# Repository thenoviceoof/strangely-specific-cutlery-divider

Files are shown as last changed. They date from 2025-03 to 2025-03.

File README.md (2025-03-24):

This is a 2D OpenSCAD plan for a cutlery divider for a very specific drawer.

The only files kept reasonably up to date are dividers.scad and dividers.dxf.

# Dimension measurements

Drawer is 248x489mm (9.76x19.25in).

2nd set of measurements is 248-249, and 483-485. Difficult to make accurate measurements in such a long drawer without taking the drawer out.
Depth is 102mm.

# Requirements

3 columns: 2 split into 2 for forks and spoons, 1 left undivided, for table knives and long chopsticks.

# Market Research

Based on [Serious Eats Review of drawer organizers](https://www.seriouseats.com/best-kitchen-drawer-organizers-8421933):

- [Option 1](https://www.amazon.com/Joseph-85119-DrawerStore-Organizer-Silverware/dp/B072R6CLRC/) Target house has way too much cutlery to fit in this narrow option.
- [Example 1](https://www.amazon.com/dp/B09B1CZVWR/): minimum width dimension is 9.8". It is theoretically possible to fit it by breaking off the expansion bit, but I'm not going to spend $22 to find out for sure.
- [Example 2](https://www.amazon.com/dp/B007B8RKJI): width dimension is 11".

Commercial versions appear to be 2.5-3in deep.

# Design considerations

[Ponoko article on kerf](https://help.ponoko.com/en/articles/4442594-how-much-material-does-the-laser-burn-away), for 3mm acrylic is 0.2mm.

[SendCutSend claims to compensate for kerf automatically](https://sendcutsend.com/blog/what-is-kerf-in-laser-cutting/).

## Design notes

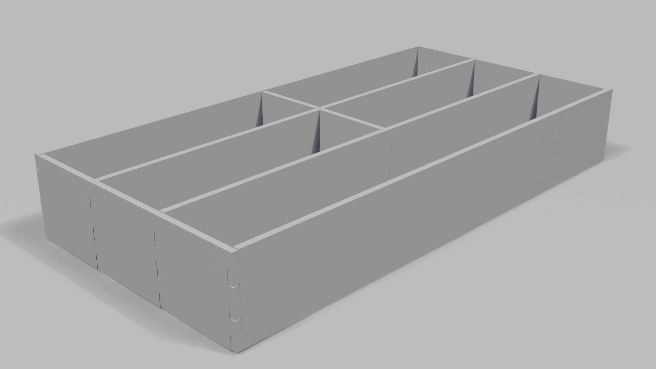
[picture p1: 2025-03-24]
img/dividers_together.png

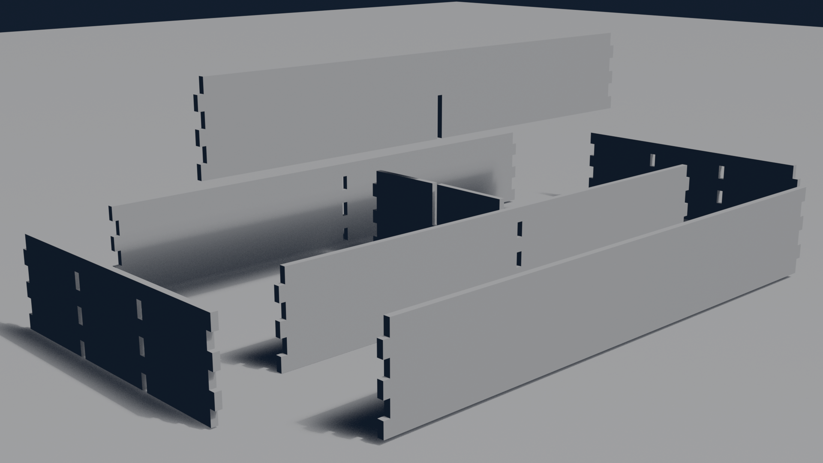
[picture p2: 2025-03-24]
img/dividers_exploded.png

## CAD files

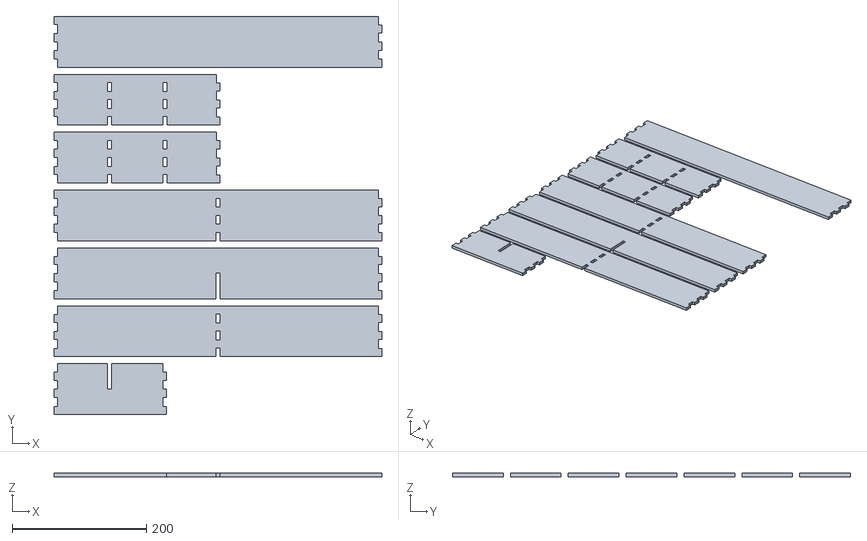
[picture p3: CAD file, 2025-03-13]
dividers.stl
488.6 x 593.0 x 5.40

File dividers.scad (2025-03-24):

// All values in mm.

/* ####################
 * Definitions.
 * #################### */

// Downsize a bit to make sure there's space.
// We can always add padding, but reducing size is basically impossible.
W = 248 - 10;
L = 483 - 20;
// 3in in height.
H = 25.4 * 2.8;

// How thick the material is.
MAT_THICK = 3;
// How wide the laser is.
// Ponoko: 0.2mm beam width.
// SendCutSend: handled automatically.
KERF = 0.1;
// Cut away just a little more, to make assembly easier/possible.
// SendCutSend MDF Tab/Slot tolerance is 0.01in, 0.25mm.
// It is possible this should be 1/2x 0.25mm.
SLOP = 0.25;
// Total adjustments: positive values cut away more.
ADJ = SLOP - KERF;

EXT_PAD = 5;

/* ####################
 * Utilities
 * #################### */

// The project is simple enough that we can get away with having all joins "point one way".
// Creates a 3 vs 3 finger box join. Fingers point to -x.
ext_box_join_a = [
    [MAT_THICK + ADJ, ADJ],
    [MAT_THICK + ADJ, 1/6 * H + ADJ],
    [ADJ,             1/6 * H + ADJ],
    [ADJ,             2/6 * H - ADJ],
    [MAT_THICK + ADJ, 2/6 * H - ADJ],
    [MAT_THICK + ADJ, 3/6 * H + ADJ],
    [ADJ,             3/6 * H + ADJ],
    [ADJ,             4/6 * H - ADJ],
    [MAT_THICK + ADJ, 4/6 * H - ADJ],
    [MAT_THICK + ADJ, 5/6 * H + ADJ],
    [ADJ,             5/6 * H + ADJ],
    [ADJ,             H - ADJ],
];
// The other side of the join.
ext_box_join_b = [ for (v = ext_box_join_a) [-v[0], -v[1] + H]];
// Bottom tooth for the left side.
ext_box_join_c = [ for (v = ext_box_join_a) [v[0], -v[1] + H]];

// "Interior" box join.
function poly_square(p1, p2) = [
    [p1[0], p1[1]],
    [p1[0], p2[1]],
    [p2[0], p2[1]],
    [p2[0], p1[1]]
];
int_box_join = concat(
    poly_square([-MAT_THICK/2 - ADJ, ADJ],
                [MAT_THICK/2 + ADJ,  1/6 * H + ADJ]),
    poly_square([-MAT_THICK/2 - ADJ, 2/6 * H - ADJ],
                [MAT_THICK/2 + ADJ,  3/6 * H + ADJ]),
    poly_square([-MAT_THICK/2 - ADJ, 4/6 * H - ADJ],
                [MAT_THICK/2 + ADJ,  5/6 * H + ADJ])
);

// Cross lap join.
cross_lap_join = poly_square([-MAT_THICK/2 - ADJ, ADJ],
                             [MAT_THICK/2 + ADJ, H / 2 + ADJ]);

/* ####################
 * Actual pieces
 * #################### */

// Right piece.
RIGHT_VEC = concat(
    ext_box_join_a,
    [ for (v = ext_box_join_b) [v[0] + L, v[1]]]
);
projection()
translate([0, 3*(H+EXT_PAD), 0])
linear_extrude(height=MAT_THICK)
polygon(RIGHT_VEC);

// Front piece.
FRONT_VEC = concat(
    ext_box_join_a,
    [ for (v = ext_box_join_b) [v[0] + W, v[1]]],
    [ for (v = int_box_join) [v[0] + W/3, v[1]]],
    [ for (v = int_box_join) [v[0] + 2*W/3, v[1]]]
);
FRONT_PATHS = [
    concat(
        [for (i = [0:11]) i],
        [for (i = [12:23]) i],
        // Square cutouts.
        [for (i = [39:-1:36]) i],
        [for (i = [27:-1:24]) i]
    ),
    [for (i = [28:31]) i],
    [for (i = [32:35]) i],
    [for (i = [40:43]) i],
    [for (i = [44:47]) i]
];
projection()
translate([W + EXT_PAD/2, 4*(H+EXT_PAD), 0])
linear_extrude(height=MAT_THICK)
polygon(FRONT_VEC, FRONT_PATHS);
    
// Use the same geometry for the back.
projection()
translate([0, 4*(H+EXT_PAD), 0])
linear_extrude(height=MAT_THICK)
polygon(FRONT_VEC, FRONT_PATHS);

// Left piece.
LEFT_VEC = concat(
    ext_box_join_a,
    [ for (v = ext_box_join_b) [v[0] + L, v[1]]],
    [ for (v = int_box_join) [v[0] + L/2, v[1]]]
);
LEFT_PATHS = [
    concat(
        [for (i = [0:11]) i],
        [for (i = [12:23]) i],
        // Square cutouts.
        [for (i = [27:-1:24]) i]
    ),
    [for (i = [28:31]) i],
    [for (i = [32:35]) i]
];
projection()
translate([0, 2*(H+EXT_PAD), 0])
linear_extrude(height=MAT_THICK)
polygon(LEFT_VEC, LEFT_PATHS);

// Column, left.
COL_LEFT_VEC = concat(
    ext_box_join_c,
    [ for (v = ext_box_join_b) [v[0] + L, v[1]]],
    [ for (v = cross_lap_join) [v[0] + L/2, v[1]]]
);
COL_LEFT_PATHS = [
    concat(
        [for (i = [11:-1:0]) i],
        [for (i = [12:23]) i],
        // Fold join.
        [for (i = [27:-1:24]) i]
    )
];
projection()
translate([0, 1*(H+EXT_PAD), 0])
linear_extrude(height=MAT_THICK)
polygon(COL_LEFT_VEC, COL_LEFT_PATHS);

// Column, right.
COL_RIGHT_VEC = concat(
    ext_box_join_c,
    [ for (v = ext_box_join_b) [v[0] + L, v[1]]],
    [ for (v = int_box_join) [v[0] + L/2, v[1]]]
);
COL_RIGHT_PATHS = [
    concat(
        [for (i = [11:-1:0]) i],
        [for (i = [12:23]) i],
        // Square cutouts.
        [for (i = [27:-1:24]) i]
    ),
    [for (i = [28:31]) i],
    [for (i = [32:35]) i]
];
projection()
translate([0, 0, 0])
linear_extrude(height=MAT_THICK)
polygon(COL_RIGHT_VEC, COL_RIGHT_PATHS);

// Cross piece.
CROSS_VEC = concat(
    ext_box_join_c,
    [ for (v = ext_box_join_b) [v[0] + 2/3 * W + MAT_THICK/2, v[1]]],
    [ for (v = cross_lap_join) [v[0] + 1/3 * W, v[1] + H / 2]]
);
CROSS_PATHS = [
    concat(
        [for (i = [11:-1:0]) i],
        // Cross lap.
        [25, 24, 27, 26],
        [for (i = [12:23]) i]
    )
];
projection()
translate([L+EXT_PAD + H, 0, 0])
rotate(90)
linear_extrude(height=MAT_THICK)
polygon(CROSS_VEC, CROSS_PATHS);

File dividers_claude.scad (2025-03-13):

// Drawer Divider System with Cross Lap and Box Joints
// Dimensions are in mm

// Main drawer dimensions
drawer_length = 489;
drawer_depth = 248;
divider_height = 3 * 25.4; // 3 inches converted to mm
material_thickness = 5.4;

// Number of divisions
columns = 3; // dividing the depth into 3 equal columns
rows = 2; // dividing 2 of the columns into 2 equal rows

// Calculate dimensions for parts
column_width = drawer_depth / columns;
row_length = drawer_length / rows;

// Box joint parameters
finger_count = 5; // Number of fingers for box joints
finger_width = divider_height / (finger_count * 2);

// Tolerance for joints (adjust as needed for your laser cutter)
tolerance = 0.1;

// Function to create points for a box joint edge
function box_joint_edge(length, num_fingers, finger_size, is_horizontal = true, is_reversed = false) = 
    let(step = length / (num_fingers * 2))
    [for (i = [0 : num_fingers * 2]) 
        is_horizontal ? 
            (is_reversed ? 
                [i * step, (i % 2 == 0) ? 0 : finger_size] :
                [i * step, (i % 2 == 0) ? finger_size : 0]) :
            (is_reversed ? 
                [(i % 2 == 0) ? 0 : finger_size, i * step] :
                [(i % 2 == 0) ? finger_size : 0, i * step])
    ];

// Panel with box joints on all sides
module exterior_panel(length, width, thickness, top_fingers = true, right_fingers = true, 
                      bottom_fingers = true, left_fingers = true) {
    finger_size = material_thickness;
    
    // Create the polygon points for the perimeter with box joints
    points = [];
    
    // Bottom edge
    bottom_edge = box_joint_edge(length, finger_count, finger_size, true, !bottom_fingers);
    
    // Right edge
    right_edge = box_joint_edge(width, finger_count, finger_size, false, right_fingers);
    for (i = [1:len(right_edge)-1]) {
        points = concat(points, [[length + right_edge[i][0], right_edge[i][1]]]);
    }
    
    // Top edge
    top_edge = box_joint_edge(length, finger_count, finger_size, true, top_fingers);
    for (i = [1:len(top_edge)-1]) {
        points = concat(points, [[length - top_edge[i][0], width + top_edge[i][1]]]);
    }
    
    // Left edge
    left_edge = box_joint_edge(width, finger_count, finger_size, false, !left_fingers);
    for (i = [1:len(left_edge)-1]) {
        points = concat(points, [[0 - left_edge[i][0], width - left_edge[i][1]]]);
    }
    
    polygon(concat([bottom_edge[0]], bottom_edge, [points[0]], points));
}

// Divider with cross lap joints
module vertical_divider(height, length, row_positions) {
    // Start with a rectangle
    points = [[0, 0], [thickness, 0], [thickness, length], [0, length]];
    
    // Cross lap cutouts
    for (pos = row_positions) {
        notch_height = material_thickness;
        notch_y = pos - notch_height/2;
        
        // This will be a complex polygon so we'll use difference() instead
        difference() {
            polygon(points);
            translate([-tolerance, notch_y])
                square([thickness + tolerance*2, notch_height]);
        }
    }
}

module horizontal_divider(length, height, column_positions) {
    // Complex shape with notches for cross laps
    difference() {
        square([length, height]);
        
        // Cut notches for vertical dividers
        for (pos = column_positions) {
            translate([pos - material_thickness/2, -tolerance])
                square([material_thickness, height + tolerance*2]);
        }
    }
}

// Layout all parts for laser cutting
module layout_for_cutting() {
    // Calculate row and column positions
    row_positions = [for (i = [1:rows-1]) i * row_length];
    column_positions = [for (i = [1:columns-1]) i * column_width];
    
    // Horizontal walls (top and bottom)
    translate([0, 0])
        exterior_panel(drawer_length, material_thickness, material_thickness, 
                     true, true, true, true);
    
    translate([0, material_thickness + 10])
        exterior_panel(drawer_length, material_thickness, material_thickness, 
                     true, true, true, true);
    
    // Vertical walls (left and right)
    translate([0, material_thickness * 2 + 20])
        exterior_panel(drawer_depth, divider_height, material_thickness, 
                     true, true, true, true);
    
    translate([drawer_depth + 10, material_thickness * 2 + 20])
        exterior_panel(drawer_depth, divider_height, material_thickness, 
                     true, true, true, true);
    
    // Vertical dividers
    for (i = [1:columns-1]) {
        translate([0, material_thickness * 2 + divider_height + 30 + (i-1) * (divider_height + 10)])
            horizontal_divider(drawer_depth, divider_height, []);
    }
    
    // Horizontal dividers (for 2 columns only)
    for (i = [1:rows-1]) {
        translate([drawer_depth + 10, material_thickness * 2 + divider_height + 30 + (columns-1) * (divider_height + 10) + (i-1) * (divider_height + 10)])
            horizontal_divider(column_width * 2, divider_height, column_positions);
    }
}

// Generate alternative design with simple tab and slot joints
module alternative_design() {
    // Vertical dividers (full height)
    for (i = [1:columns-1]) {
        x = i * column_width;
        translate([x - material_thickness/2, 0, 0]) {
            difference() {
                square([material_thickness, drawer_depth]);
                
                // Slots for horizontal dividers
                for (j = [1:rows-1]) {
                    if (x <= column_width * 2) { // Only for first two columns
                        y = j * row_length;
                        translate([-tolerance, y - material_thickness/2])
                            square([material_thickness + tolerance*2, material_thickness]);
                    }
                }
            }
        }
    }
    
    // Horizontal dividers (for first two columns only)
    for (j = [1:rows-1]) {
        y = j * row_length;
        translate([0, y - material_thickness/2, 0]) {
            difference() {
                square([column_width * 2, material_thickness]);
                
                // Slots for vertical dividers
                for (i = [1:columns-1]) {
                    x = i * column_width;
                    if (x <= column_width * 2) { // Only for dividers within range
                        translate([x - material_thickness/2, -tolerance])
                            square([material_thickness, material_thickness + tolerance*2]);
                    }
                }
            }
        }
    }
    
    // Outer frame
    difference() {
        square([drawer_length, drawer_depth]);
        translate([material_thickness, material_thickness])
            square([drawer_length - material_thickness*2, drawer_depth - material_thickness*2]);
        
        // Slots for vertical dividers in outer frame
        for (i = [1:columns-1]) {
            x = i * column_width;
            
            // Bottom edge
            translate([x - material_thickness/2, 0])
                square([material_thickness, material_thickness]);
            
            // Top edge
            translate([x - material_thickness/2, drawer_depth - material_thickness])
                square([material_thickness, material_thickness]);
        }
        
        // Slots for horizontal dividers in outer frame
        for (j = [1:rows-1]) {
            y = j * row_length;
            
            // Left edge (only for dividers in first two columns)
            translate([0, y - material_thickness/2])
                square([material_thickness, material_thickness]);
            
            // Right edge of second column
            translate([column_width * 2 - material_thickness, y - material_thickness/2])
                square([material_thickness, material_thickness]);
        }
    }
}
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

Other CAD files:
dividers.blend
dividers.dxf

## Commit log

2025-03-12 AI: Claude 1-shot, but it doesn't successfully export from OpenSCAD
    [dividers_claude.scad]
2025-03-12 AI: 2nd shot, which does export successfully but the output is unusable
    [dividers_claude.scad]
2025-03-13 AI: try to get Claude to fix problems, no success
    [dividers_claude.scad]
2025-03-13 Manually create plans, exports use 0.2mm adjust
    [dividers.scad, dividers.stl]
2025-03-13 Adjust cross piece to lap the other way
    [dividers.scad, dividers.stl]
2025-03-13 Internal cross piece didn't extend far enough
    [dividers.scad, dividers.stl]
2025-03-13 Pre-viz the build
    [dividers.blend]
2025-03-13 Export to dxf for sendcutsend
    [dividers.dxf]
2025-03-14 Rearrange pieces to take up less space
    [dividers.dxf, dividers.scad]
2025-03-14 Use 3mm material
    [dividers.dxf, dividers.scad]
2025-03-14 Adjust and export for 3.2mm MDF
    [dividers.dxf, dividers.scad]
2025-03-14 Shrink major dimensions a bit, to make sure it fits
    [dividers.dxf, dividers.scad]
2025-03-17 Adjust for Ponoko acrylic
    [dividers.dxf, dividers.scad]
2025-03-24 Adjust sizing, and reduce major dimension sizes more to ensure fit
    [dividers.dxf, dividers.scad]
2025-03-24 Add some clarification around slop measurement
    [dividers.scad]
